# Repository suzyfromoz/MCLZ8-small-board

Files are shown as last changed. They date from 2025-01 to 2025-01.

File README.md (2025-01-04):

# MCLZ8-small-board
A small interface board between a Teensy 4.1 and a Z80 socket to run MCLZ8 code

Two boards are presented - MCLZ8_PCB fits in the same footprint as The Teensy 4.1 and performs the functionality of @MicroCoreLabs MCLZ8 board, in providing the bus buffering for the Teensy. The Schematic is unchanged from @MicroCoreLabs MCLZ8. The 40 pin probing adapter B board goes underneath, and simply adapts the 40 pin header from the first board back to 0.6" hole centers, so we can plug it into a Z80 socket.

The MCLZ8_PCB is four layers, while the probing adapter board is two.

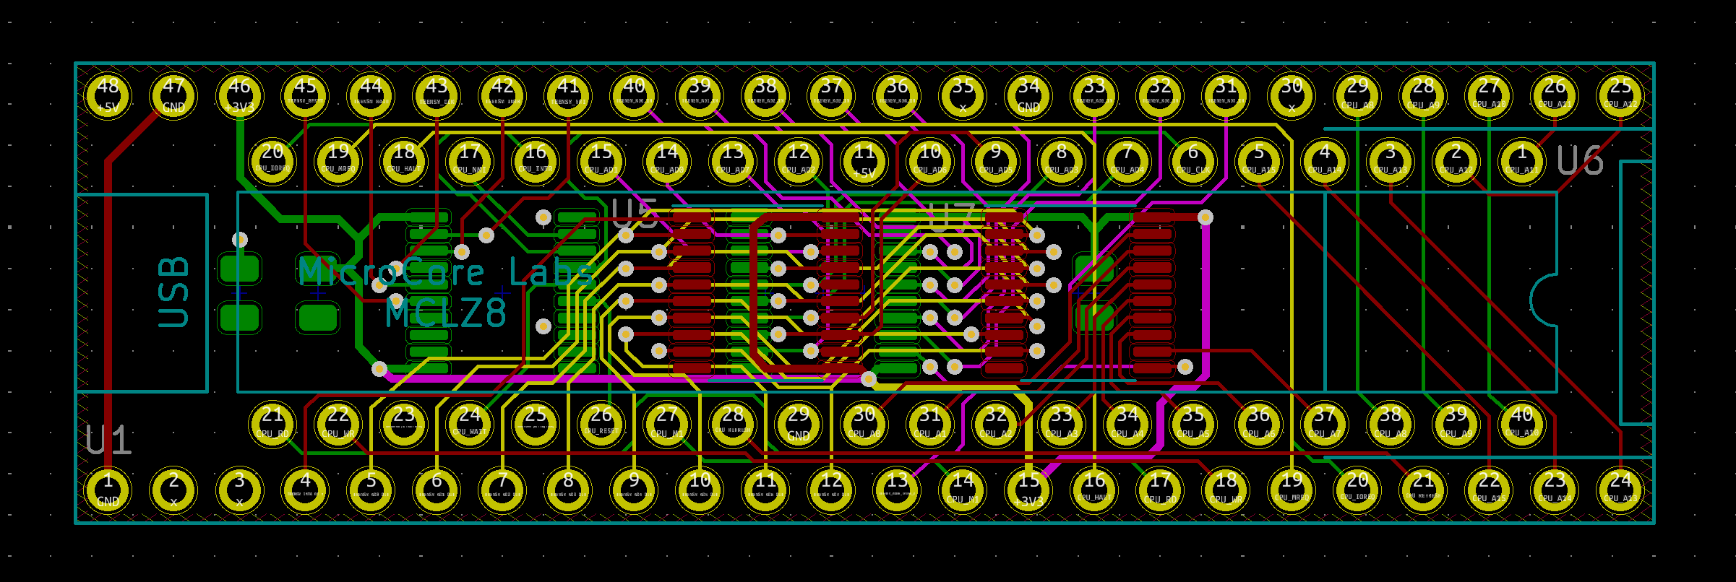
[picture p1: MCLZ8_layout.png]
Screengrab of MCLZ8 board


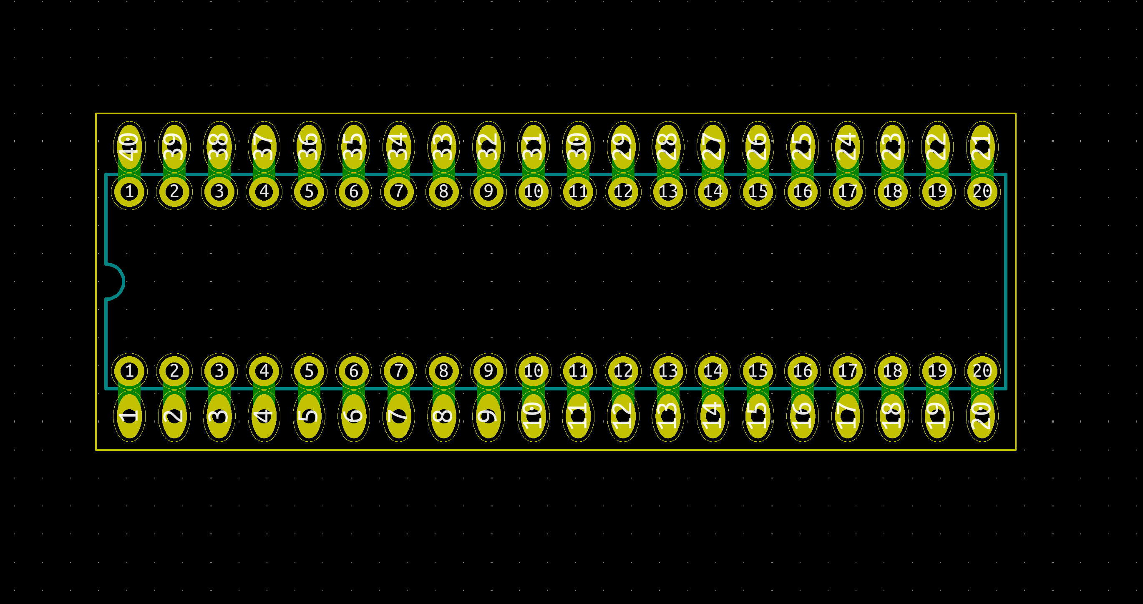
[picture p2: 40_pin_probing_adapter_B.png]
Screengrab of Probing adapter board


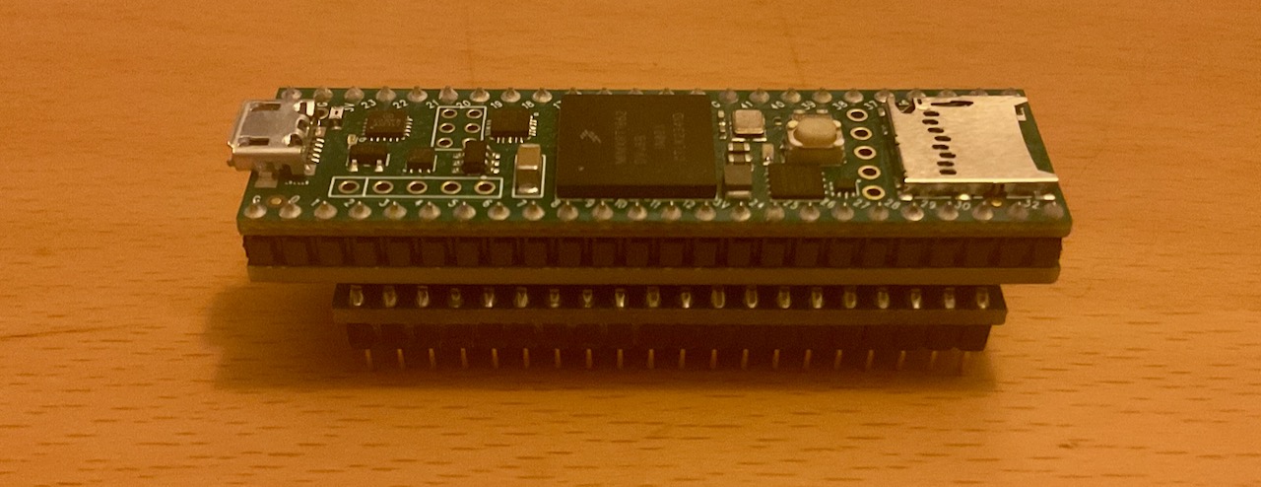
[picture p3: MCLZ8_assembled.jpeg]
Photograph of completed assembly under Teensy 4.1


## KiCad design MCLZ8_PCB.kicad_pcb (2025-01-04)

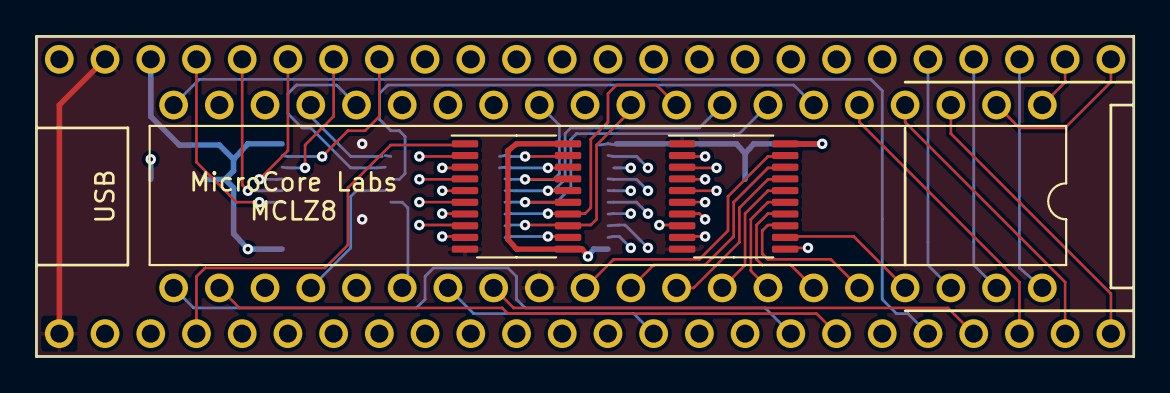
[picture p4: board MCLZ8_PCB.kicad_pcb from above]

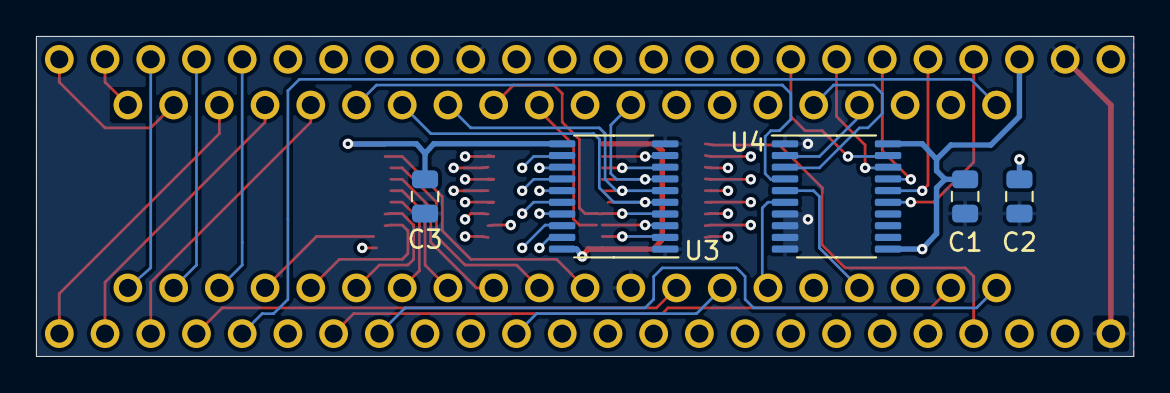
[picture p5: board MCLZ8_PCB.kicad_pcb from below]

Board: 4 copper layers, 61.0 x 17.8 mm, 9 parts (5 on the bottom side), 62 nets.

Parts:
C1, C2, C3: 100n; C_0805_2012Metric
U1: Teensy4.1; Teensy41_Ted_Modified
U3, U4, U5, U7: SN74LVC573A; TSSOP-20_4.4x6.5mm_P0.65mm
U6: Z80CPU; DIP-40_W15.24mm

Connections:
+3V3: C1.1, C3.1, U1.15 (3V3), U1.46 (3V3), U3.11 (Load), U3.20 (VCC), U4.11 (Load), U4.20 (VCC), U5.11 (Load), U5.20 (VCC), U7.20 (VCC)
+5V: C2.1, U1.48 (VIN), U6.11 (VCC)
CPU_A0: U6.30 (A0), U7.19 (Q0)
CPU_A1: U6.31 (A1), U7.18 (Q1)
CPU_A2: U6.32 (A2), U7.17 (Q2)
CPU_A3: U6.33 (A3), U7.16 (Q3)
CPU_A4: U6.34 (A4), U7.15 (Q4)
CPU_A5: U6.35 (A5), U7.14 (Q5)
CPU_A6: U6.36 (A6), U7.13 (Q6)
CPU_A7: U6.37 (A7), U7.12 (Q7)
CPU_A8: U1.29 (37_CS), U6.38 (A8)
CPU_A9: U1.28 (36_CS), U6.39 (A9)
CPU_A10: U1.27 (35_TX8), U6.40 (A10)
CPU_A11: U1.26 (34_RX8), U6.1 (A11)
CPU_A12: U1.25 (33_MCLK2), U6.2 (A12)
CPU_A13: U1.24 (32_OUT1B), U6.3 (A13)
CPU_A14: U1.23 (31_CTX3), U6.4 (A14)
CPU_A15: U1.22 (30_CRX3), U6.5 (A15)
CPU_AD0: U3.9 (D7), U5.19 (Q0), U6.14 (D0)
CPU_AD1: U3.8 (D6), U5.18 (Q1), U6.15 (D1)
CPU_AD2: U3.7 (D5), U5.17 (Q2), U6.12 (D2)
CPU_AD3: U3.6 (D4), U5.16 (Q3), U6.8 (D3)
CPU_AD4: U3.5 (D3), U5.15 (Q4), U6.7 (D4)
CPU_AD5: U3.4 (D2), U5.14 (Q5), U6.9 (D5)
CPU_AD6: U3.3 (D1), U5.13 (Q6), U6.10 (D6)
CPU_AD7: U3.2 (D0), U5.12 (Q7), U6.13 (D7)
CPU_CLK: U4.4 (D2), U6.6 (~CLK)
CPU_HALT: U1.16 (24_A10_TX6_SCL2), U6.18 (~HALT)
CPU_INTR: U4.3 (D1), U6.16 (~INT)
CPU_IOREQ: U1.20 (28_RX7), U6.20 (~IORQ)
CPU_M1: U1.14 (12_MISO_MQSL), U6.27 (~M1)
CPU_MREQ: U1.19 (27_A13_SCK1), U6.19 (~MREQ)
CPU_NMI: U4.2 (D0), U6.17 (~NMI)
CPU_RD: U1.17 (25_A11_RX6_SDA2), U6.21 (~RD)
CPU_REFRESH: U1.21 (29_TX7), U6.28 (~RFSH)
CPU_RESET: U4.6 (D4), U6.26 (~RESET)
CPU_WAIT: U4.5 (D3), U6.24 (~WAIT)
CPU_WR: U1.18 (26_A12_MOSI1), U6.22 (~WR)
GND: C1.2, C2.2, C3.2, U1.1 (GND), U1.34 (GND), U1.47 (GND), U3.1 (OE), U3.10 (GND), U4.1 (OE), U4.7 (D5), U4.8 (D6), U4.9 (D7), U4.10 (GND), U5.10 (GND), U6.29 (GND), U7.1 (OE), U7.10 (GND)
TEENSY_AD0_IN: U1.40 (18_A4_SDA), U3.12 (Q7)
TEENSY_AD0_OUT: U1.5 (3_LRCLK2), U5.2 (D0), U7.2 (D0)
TEENSY_AD1_IN: U1.39 (17_A3_TX4_SDA1), U3.13 (Q6)
TEENSY_AD1_OUT: U1.6 (4_BCLK2), U5.3 (D1), U7.3 (D1)
TEENSY_AD2_IN: U1.38 (16_A2_RX4_SCL1), U3.14 (Q5)
TEENSY_AD2_OUT: U1.7 (5_IN2), U5.4 (D2), U7.4 (D2)
TEENSY_AD3_IN: U1.37 (15_A1_RX3_SPDIF_IN), U3.15 (Q4)
TEENSY_AD3_OUT: U1.8 (6_OUT1D), U5.5 (D3), U7.5 (D3)
TEENSY_AD4_IN: U1.36 (14_A0_TX3_SPDIF_OUT), U3.16 (Q3)
TEENSY_AD4_OUT: U1.9 (7_RX2_OUT1A), U5.6 (D4), U7.6 (D4)
TEENSY_AD5_IN: U1.33 (41_A17), U3.17 (Q2)
TEENSY_AD5_OUT: U1.10 (8_TX2_IN1), U5.7 (D5), U7.7 (D5)
TEENSY_AD6_IN: U1.32 (40_A16), U3.18 (Q1)
TEENSY_AD6_OUT: U1.11 (9_OUT1C), U5.8 (D6), U7.8 (D6)
TEENSY_AD7_IN: U1.31 (39_MISO1_OUT1A), U3.19 (Q0)
TEENSY_AD7_OUT: U1.12 (10_CS_MQSR), U5.9 (D7), U7.9 (D7)
TEENSY_ADDR_LATCH_n: U1.13 (11_MOSI_CTX1), U7.11 (Load)
TEENSY_CLK: U1.43 (21_A7_RX5_BCLK1), U4.17 (Q2)
TEENSY_DATA_OE_n: U1.4 (2_OUT2), U5.1 (OE)
TEENSY_INTR: U1.42 (20_A6_TX5_LRCLK1), U4.18 (Q1)
TEENSY_NMI: U1.41 (19_A5_SCL), U4.19 (Q0)
TEENSY_RESET: U1.45 (23_A9_CRX1_MCLK1), U4.15 (Q4)
TEENSY_WAIT: U1.44 (22_A8_CTX1), U4.16 (Q3)
